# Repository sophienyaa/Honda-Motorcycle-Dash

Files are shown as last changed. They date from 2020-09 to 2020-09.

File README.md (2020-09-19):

# Honda Motorcycle Dash

**NOTE: This is a 'Alpha' and a work in progress**



## What is this?

This is my attempt to build an information display / dashboard replacement (or additon) for modern Honda motorcycles. It connects to the bike via its diagnostic port and reads information directly from the ECU

It also contains a GPS module and support for an ambient temperature / humidity sensor

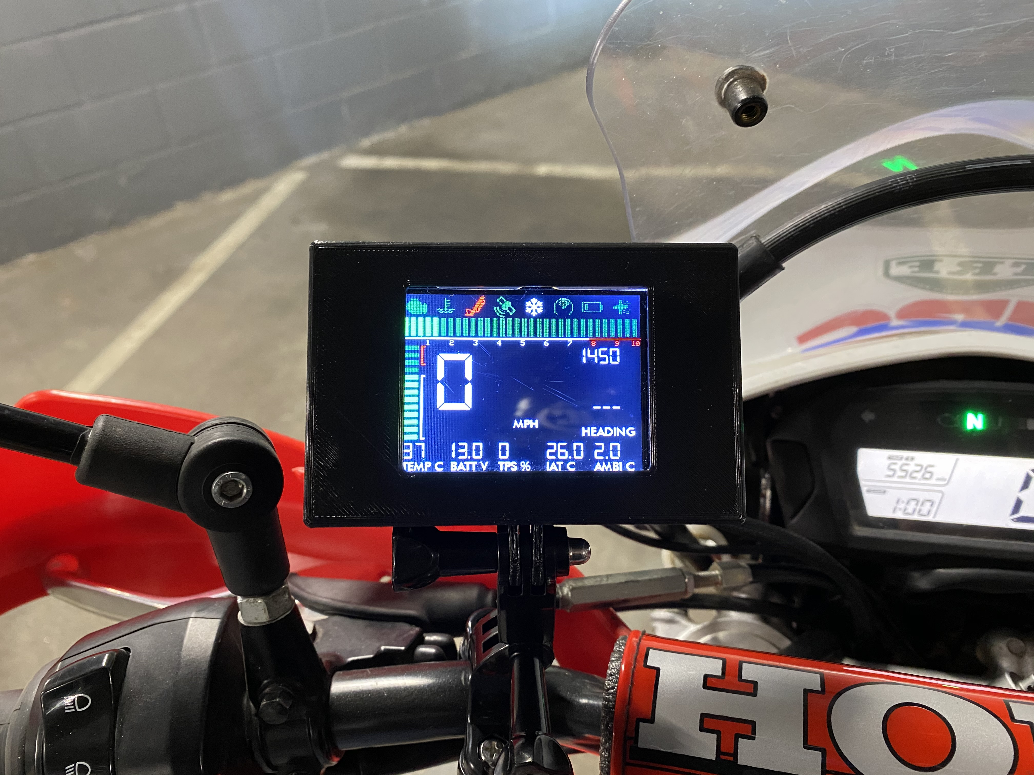
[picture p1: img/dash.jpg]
The Display Device


## Hardware

The below hardware is used in the current design. For further information see the [hardware](https://github.com/mickwheelz/Honda-Motorcycle-Dash/wiki/Hardware) section of the wiki

* Espressif ESP32 (Node32S for development, ESP32WROOM for build)
* 2.8" ILI9341 based SPI TFT Display
* DHT22 Temperature/Humidity Sensor
* Serial GPS Module
* L9637D Monolithic bus driver with ISO 9141 interface

Eagle CAD files for the hardware are available in the `pcb` folder, and designs for 3D printing a housing are available in the `case` folder

## Software & Features

The code is written for the ESP32 in C\C++ and is designed to be built with PlatformIO

On startup the device connects to the bike's ECU and displays the following information

* Engine Temperature
* Engine RPM
* Battery Voltage
* Throttle Position %
* Intake Air Temperature C
* Neutral Switch
* Side Stand Switch
* Bike Speed

It also displays the following information from other sensors

* GPS Speed (GPS)
* Ambient Temperature (DHT22)

The below features are intended to be available in the future

* Gear Position (Based on Speed + RPM) (ECU)
* Heading (North, South, East, West, etc) (GPS)
* Ambient Humidity (DHT22)
* Smartphone Notifications (ESP32 BLE)
* Smartphone "Now Playing" (ESP32 BLE)

For further information, see the [software](https://github.com/mickwheelz/Honda-Motorcycle-Dash/wiki/Software) section of the wiki section of the wiki

## Special Thanks To

This project would not be possible without the below information and open source code

Working with Honda ECU's
* Aster94's KWP2000 Library - https://github.com/aster94/Keyword-Protocol-2000
* Gonzo's CTX-OBD Project - https://gonzos.net/projects/ctx-obd/
* PGMFI Formus - http://forum.pgmfi.org/

Arduino Libraries and Tools
* Adafruit's GFX/DHT/ILI9341/BusIO Libraries - https://learn.adafruit.com/adafruit-gfx-graphics-library/overview
* Mikalhart's TinyGPS++ - https://github.com/mikalhart/TinyGPSPlus
* Javl's image2cpp - https://javl.github.io/image2cpp/
* Ropg's truetype2gfx - https://rop.nl/truetype2gfx/

## Disclaimer

This code is provided under the GNU GPLv3 and includes NO WARRANTY.

The authors accept NO LIABILITY for damages or destruction to any property or persons through the use of this software or hardware design.

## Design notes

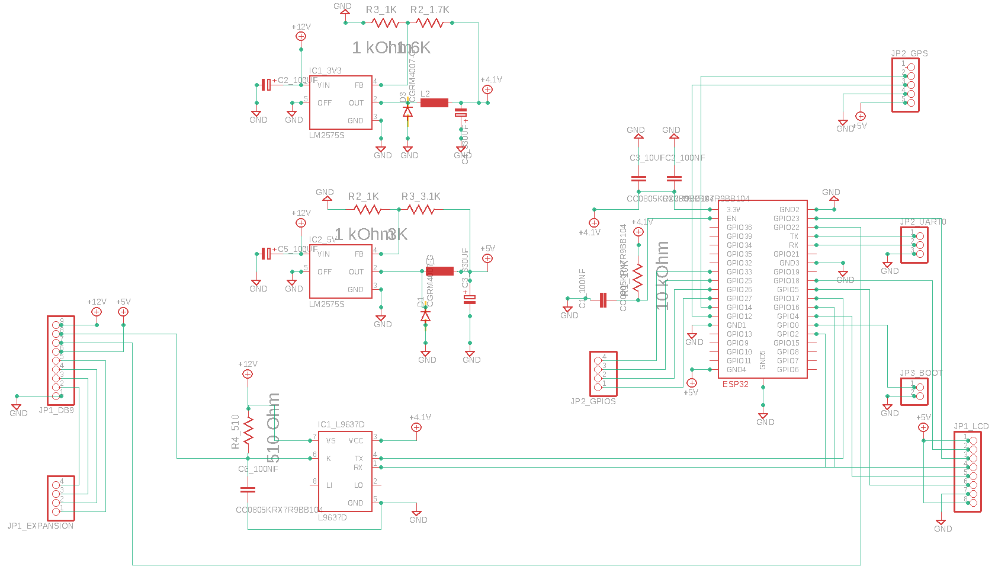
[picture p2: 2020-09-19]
img/schematic.png

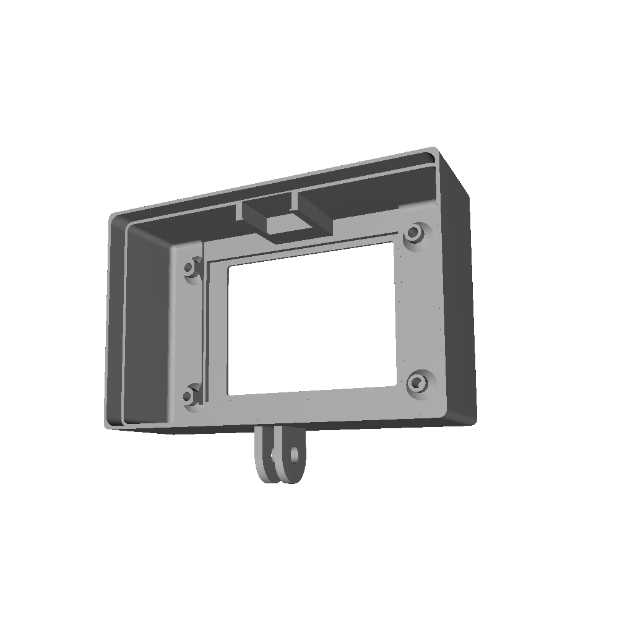
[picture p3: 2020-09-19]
img/front1.png

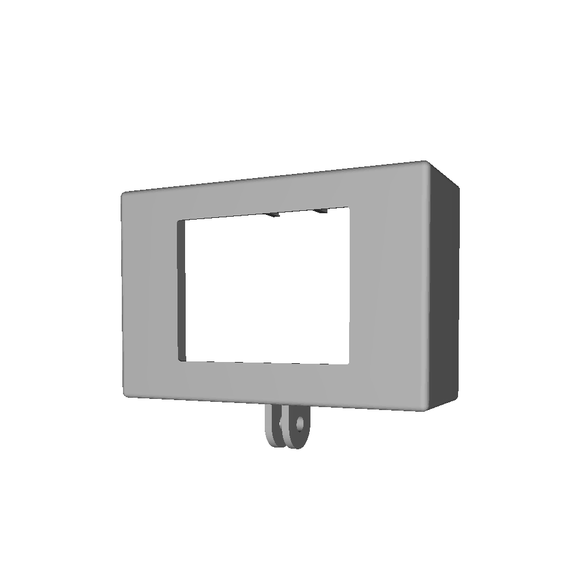
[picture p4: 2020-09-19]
img/front2.png

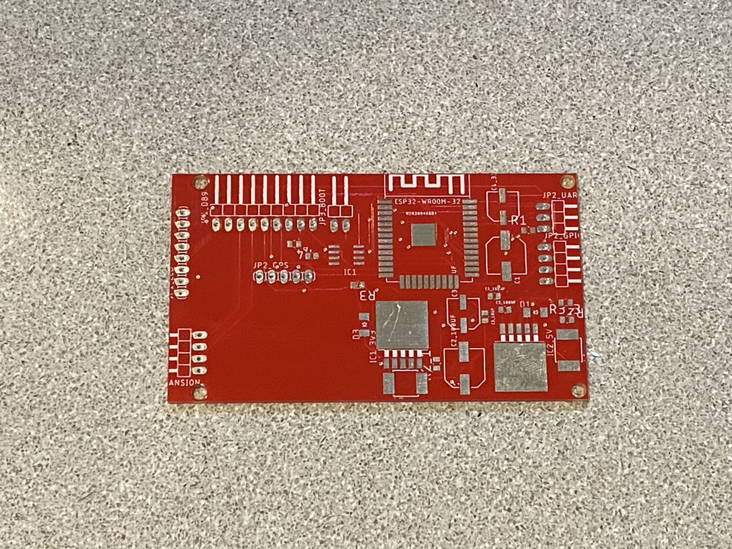
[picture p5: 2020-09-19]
img/pcb.jpg

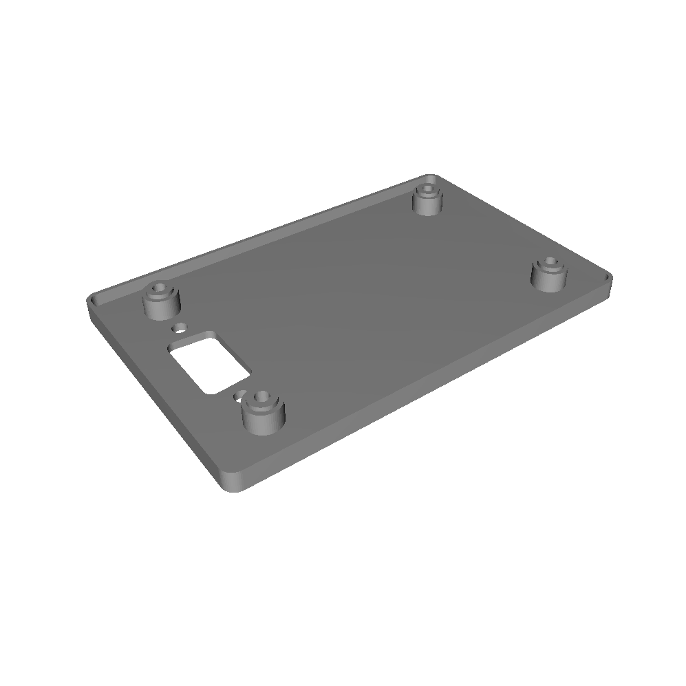
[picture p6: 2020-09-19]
img/backimage.png

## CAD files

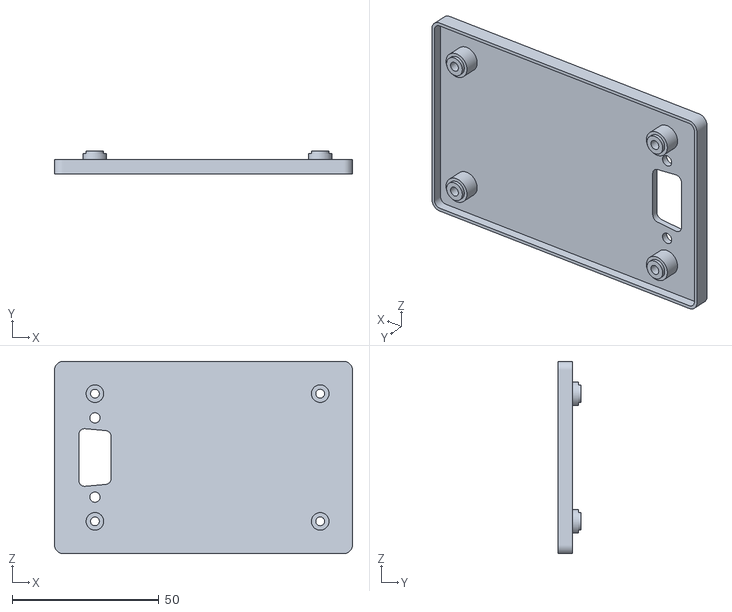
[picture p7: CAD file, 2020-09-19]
case/bike-ecu-display-holder-back.stl
101.5 x 8.00 x 65.5

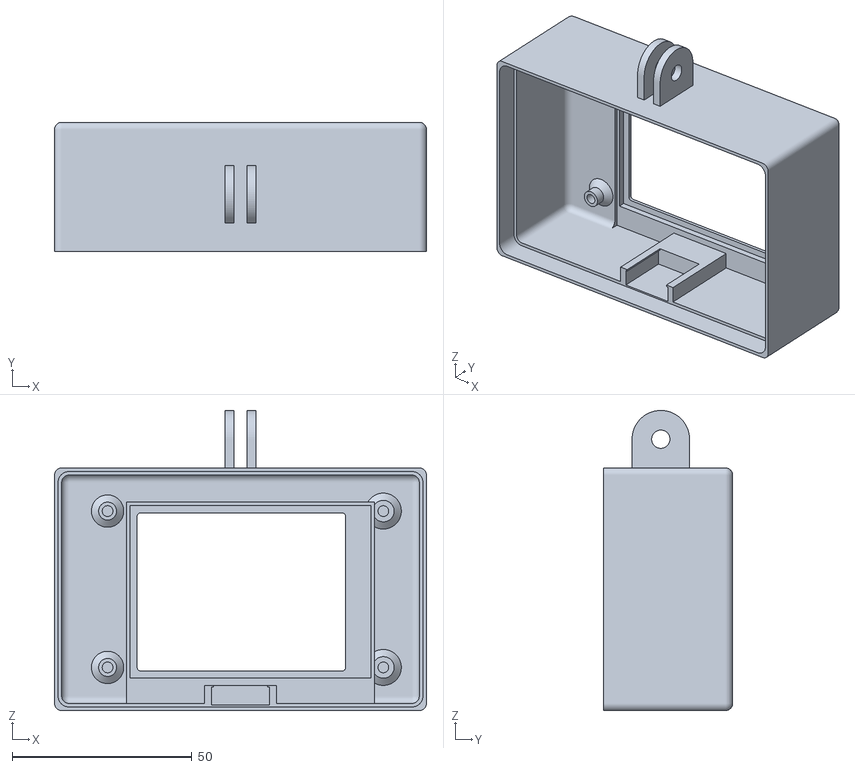
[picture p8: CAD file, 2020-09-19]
case/bike-ecu-display-holder-front.stl
103.5 x 36.0 x 83.5

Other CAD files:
case/bike-ecu-display-holder v19.f3d

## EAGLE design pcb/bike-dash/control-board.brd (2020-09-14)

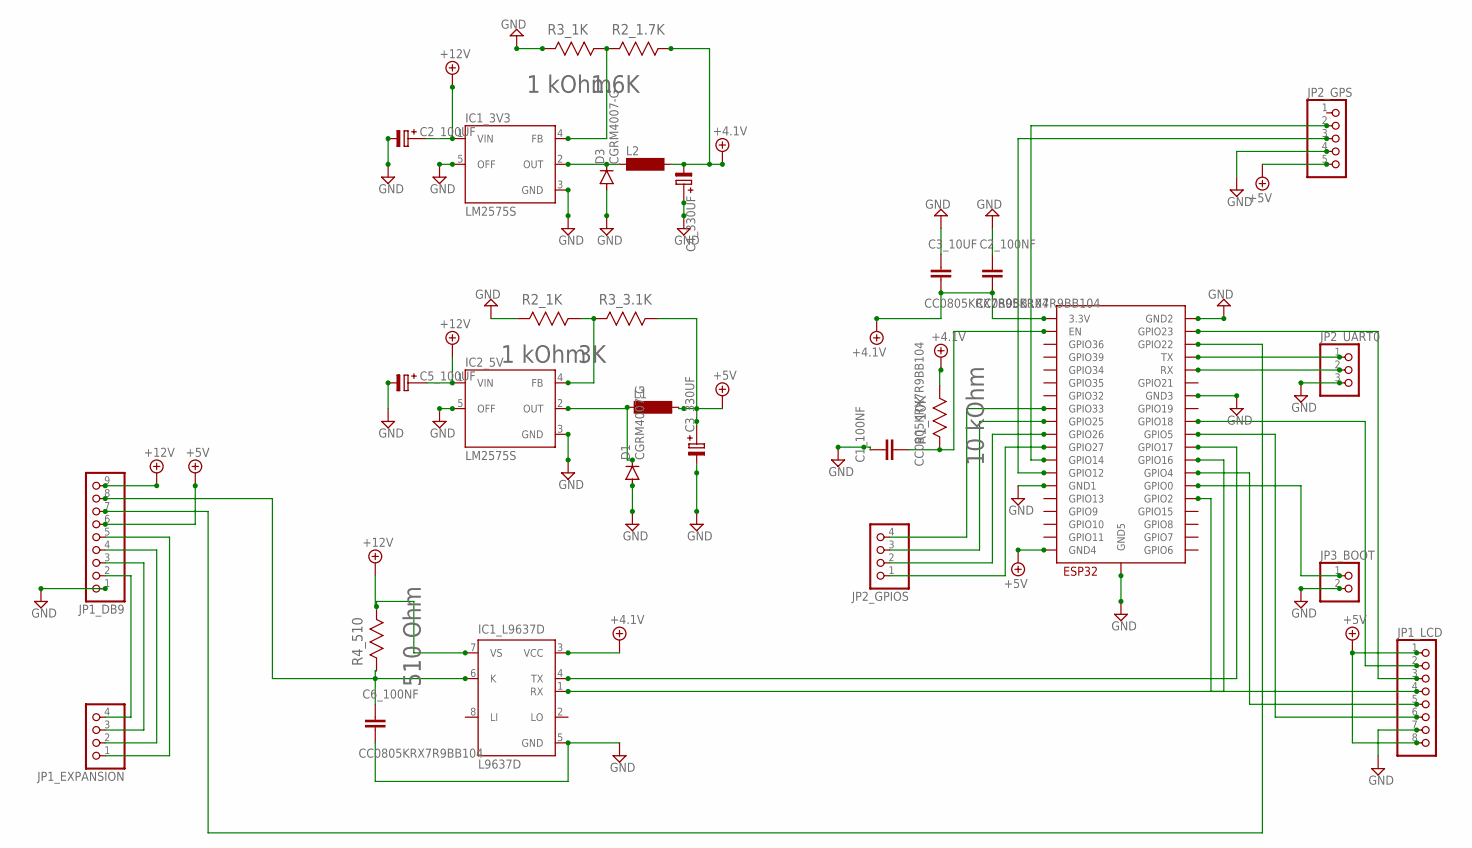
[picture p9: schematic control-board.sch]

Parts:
C1_100NF, C2_100NF, C3_10UF, C6_100NF: CC0805KRX7R9BB104; CAP_0805
C2_100UF, C5_100UF: C-PR-SMD-SV-E/F; SV-E/F
C3_330UF, C4_330UF: C-PR-SMD-SV-D; SV-D
D1, D3: CGRM4007-G; SOD-123_MINI-SMA
ESP32: ESP32-WROOM
IC1_3V3, IC2_5V: LM2575S; TO263-5
IC1_L9637D: L9637D; SO08
JP1_DB9: PINHD-1X9/90; 1X09/90
JP1_EXPANSION, JP2_GPIOS: PINHD-1X4/90; 1X04/90
JP1_LCD: PINHD-1X8; 1X08
JP2_GPS: PINHD-1X5; 1X05
JP2_UART0: PINHD-1X3/90; 1X03/90
JP3_BOOT: PINHD-1X2/90; 1X02/90
L1, L2: MS85
R1_10K: 10 kOhm; RESC2013X65N
R2_1.7K: 1.6K; RESC2013X65N
R2_1K, R3_1K: 1 kOhm; RESC2013X65N
R3_3.1K: 3K; RESC2013X65N
R4_510: 510 Ohm; RESC2013X65N

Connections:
+4.1V: C2_100NF.2, C3_10UF.2, C4_330UF.-, ESP32.3V3 (3.3V), IC1_L9637D.3 (VCC), L2.2, R1_10K.1 (R1), R2_1.7K.1 (R1)
+5V: C3_330UF.+, ESP32.GND4, JP1_DB9.6, JP1_LCD.1, JP1_LCD.8, JP2_GPS.5, L1.2, R3_3.1K.1 (R1)
+12V: C2_100UF.+, C5_100UF.+, IC1_3V3.1 (VIN), IC1_L9637D.7 (VS), IC2_5V.1 (VIN), JP1_DB9.9, R4_510.1 (R1)
GND: C1_100NF.1, C2_100NF.1, C2_100UF.-, C3_10UF.1, C3_330UF.-, C4_330UF.+, C5_100UF.-, C6_100NF.2, D1.A, D3.A, ESP32.GND1, ESP32.GND2, ESP32.GND3, ESP32.GND5, IC1_3V3.3 (GND), IC1_3V3.5 (OFF), IC1_L9637D.5 (GND), IC2_5V.3 (GND), IC2_5V.5 (OFF), JP1_DB9.1, JP1_LCD.7, JP2_GPS.4, JP2_UART0.3, JP3_BOOT.2, R2_1K.2 (R2), R3_1K.2 (R2)
unnamed: C1_100NF.2, ESP32.EN, R1_10K.2 (R2)
unnamed: D3.C, IC1_3V3.2 (OUT), L2.1
unnamed: C6_100NF.1, IC1_L9637D.6 (K), JP1_DB9.8, R4_510.2 (R2)
unnamed: D1.C, IC2_5V.2 (OUT), L1.1
unnamed: IC1_3V3.4 (FB), R2_1.7K.2 (R2), R3_1K.1 (R1)
unnamed: ESP32.IO0 (GPIO0), JP3_BOOT.1
unnamed: ESP32.TX, JP2_UART0.1
unnamed: ESP32.RX, JP2_UART0.2
unnamed: IC2_5V.4 (FB), R2_1K.1 (R1), R3_3.1K.2 (R2)
unnamed: ESP32.IO22 (GPIO22), JP1_DB9.7
unnamed: JP1_DB9.2, JP1_EXPANSION.4
unnamed: ESP32.IO17 (GPIO17), IC1_L9637D.4 (TX)
unnamed: ESP32.IO16 (GPIO16), IC1_L9637D.1 (RX)
unnamed: ESP32.IO12 (GPIO12), JP2_GPS.3
unnamed: ESP32.IO14 (GPIO14), JP2_GPS.2
unnamed: JP1_DB9.3, JP1_EXPANSION.3
unnamed: JP1_DB9.4, JP1_EXPANSION.2
unnamed: JP1_DB9.5, JP1_EXPANSION.1
unnamed: ESP32.IO5 (GPIO5), JP1_LCD.6
unnamed: ESP32.IO4 (GPIO4), JP1_LCD.5
unnamed: ESP32.IO2 (GPIO2), JP1_LCD.4
unnamed: ESP32.IO23 (GPIO23), JP1_LCD.3
unnamed: ESP32.IO18 (GPIO18), JP1_LCD.2
unnamed: ESP32.IO27 (GPIO27), JP2_GPIOS.1
unnamed: ESP32.IO26 (GPIO26), JP2_GPIOS.2
unnamed: ESP32.IO25 (GPIO25), JP2_GPIOS.3
unnamed: ESP32.IO33 (GPIO33), JP2_GPIOS.4

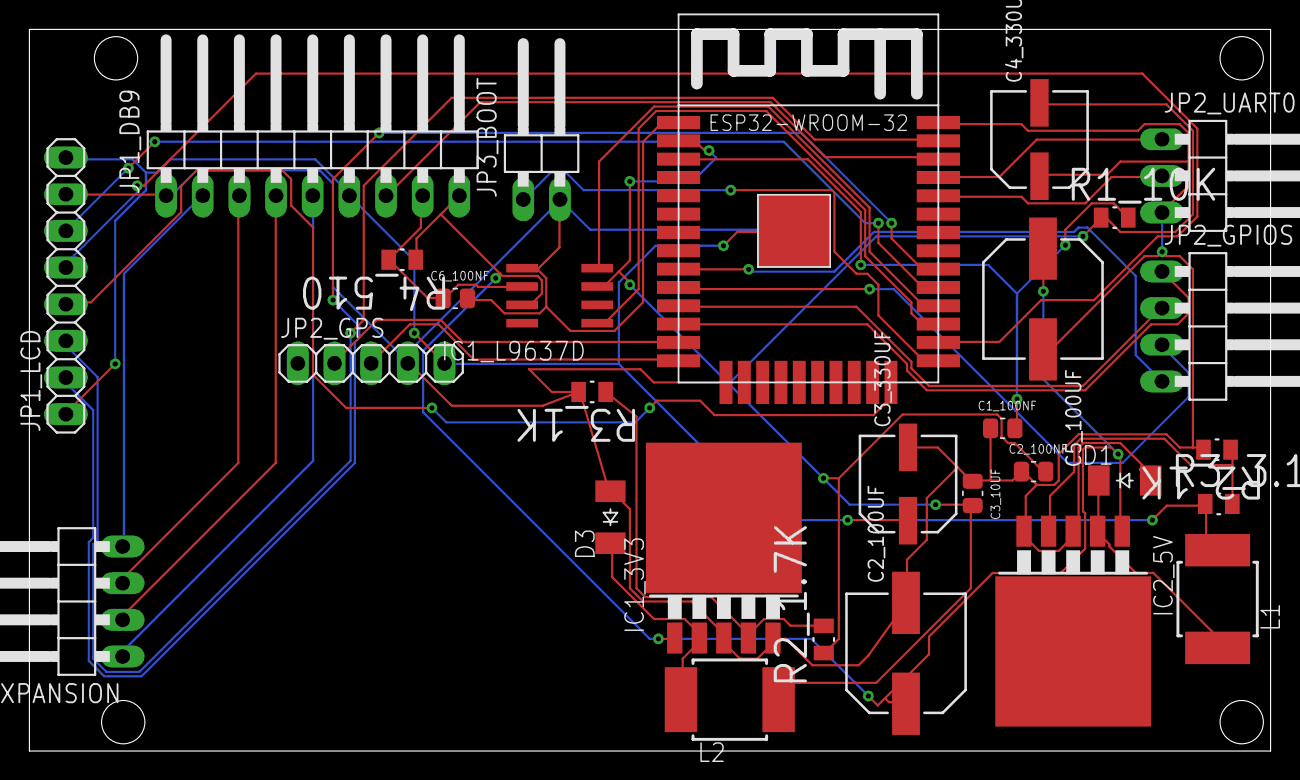
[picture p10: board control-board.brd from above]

Board: 2 copper layers, 86.0 x 50.0 mm, 29 parts (0 on the bottom side), 31 nets.

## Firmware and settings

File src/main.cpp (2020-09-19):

#include <Arduino.h>
#include "utils.h"
#include "graphics.h"
#include "ecu.h"
#include "dht.h"
#include "gps.h"

//Flag for debug mode, prints to UART0
#define DEBUG true
//Flag for bike, if false sets fake values on display for bench testing
#define BIKE true

int ecuConnected = 0;

void printDebugValues();

void setup() {
  setupDHT();
  setupGPS();
  setupDisplay();
  ecuConnected = setupECU(DEBUG);
  setupUI();
  delay(50);
}

void loop() {

TABLE11RESPONSE table11;
TABLED1RESPONSE tableD1;
DHTRESPONSE dhtValues;
GPSRESPONSE gpsValues;

  if(BIKE) {
    table11 = showDataTable11();
    tableD1 = showDataTableD1();
    dhtValues = getDHTValues();
    gpsValues = readGPS();
  }
  else {
    //set some values for testing display
    table11.rpm = 10000;
    table11.ectTemp = 120;
    dhtValues.tempC = 2.5;
    table11.battVolts = 11.9;
    table11.tpsPercent = 69;
    table11.iatTemp = 45;
    gpsValues.speedMPH = 100;
    table11.speedKPH = 105;
    tableD1.engState = 1;
    tableD1.switchState = 3;
  }
  
  //draw code
  drawRPMBar(table11.rpm);
  drawTempBar(table11.ectTemp);
  drawAmbiTemp(dhtValues.tempC);
  drawBattVolt(table11.battVolts);
  drawTPS(table11.tpsPercent);
  drawIATC(table11.iatTemp);
  drawSidestandIcon(tableD1.switchState);
  drawEngineIcon(tableD1.engState);
  drawGPSIcon(gpsValues.gpsLock);
  drawSpeed(gpsValues.speedKPH, table11.speedKPH);
  drawCardinal(gpsValues.cardinalDirection);

  //TODO: Implement below methods, set to 0 so show as off
  //drawGear(0);
  //drawFanIcon(0);

  if(DEBUG) {
    printDebugValues();
  }
}

void printDebugValues() {
  //TODO: this
}

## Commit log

2020-09-12 add eagle cad files for PCB
    [control-board.brd, control-board.sch]
2020-09-14 changes to pcb
    [control-board.brd]
2020-09-18 changes after test run, kph to mph, tps correction
    [main.cpp]
2020-09-19 add case 3d files
    [bike-ecu-display-holder v19.f3d, bike-ecu-display-holder-back.stl, bike-ecu-display-holder-front.stl]
2020-09-19 fixes for gps and dht
    [main.cpp]

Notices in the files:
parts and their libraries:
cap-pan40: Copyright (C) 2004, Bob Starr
